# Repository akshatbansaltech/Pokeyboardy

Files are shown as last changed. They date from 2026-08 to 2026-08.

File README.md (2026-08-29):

# Pokeyboardy

<p align="center">
  <a href="https://kicanvas.org/?repo=https://github.com/akshatbansaltech/Pokeyboardy/tree/main/pcb">
    
  </a>
</p>

**Pokeyboardy** is a compact 5-key macropad which features five mechanical switches, a rotary encoder, RGB lighting, and support for a small OLED display, all powered by a Seeed Studio XIAO RP2040. The PCB, case, and knob were designed from scratch as part of the project.
The cherry on top is that its pokemon inspired!!!(yayyayay), hence the name.

POKEYBOARDY IS APPROVED IN STARDANCE!!!!!!

## Features

- 5x Cherry MX switches
- 1x EC11 rotary encoder
- 3x SK6812 mini RGB LEDs
- Seeed XIAO controller
- OLED header

## Contents

| File | What it is |
|---|---|
| [Pokeyboardy.kicad_sch](Pokeyboardy.kicad_sch) | Schematic |
| [Pokeyboardy.kicad_pcb](Pokeyboardy.kicad_pcb) | Board layout |
| [Pokeyboardy Full w components.step](Pokeyboardy%20Full%20w%20components.step) | Full case assembly |
| [Pokeyboardy Full Case.step](Pokeyboardy%20Full%20Case.step) | Case only |
| [Pokeyboardy PCB.step](Pokeyboardy%20PCB.step) | PCB model |
| [Pokeyboardy knob.step](Pokeyboardy%20knob.step) | Rotary knob |
| [production/](production/) | Gerbers zip, drill file, 3D-printable case STL files (Body/Top/Middle) + firmware |
| [Pokeyboardy.csv](Pokeyboardy.csv) | Component BOM |
| [lib/](lib/) | Footprints and 3D models used by the project |

## BOM

| Reference | Value | Footprint | Qty |
|---|---|---|-----|
| D1-D4, D8, D10 | 1N4148 DO-35 diode | Diode_THT:D_DO-35_SOD27_P7.62mm_Horizontal | 6 |
| D5, D6, D9 | SK6812 mini | LED_SMD:LED_SK6812MINI-E_3.2x2.8mm_P1.5mm_ReverseMount | 3 |
| J1 | OLED display header | Connector_PinHeader_2.54mm:PinHeader_1x04_P2.54mm_Vertical | 1 |
| SW1 | EC11 rotary encoder | Rotary_Encoder:RotaryEncoder_Alps_EC11E-Switch_Vertical_H20mm | 1 |
| SW2-SW6 | Cherry MX switch | Button_Switch_Keyboard:SW_Cherry_MX_1.00u_PCB | 5 |
| U1 | Seeed Studio XIAO RP2040 | XIAO-Generic-Hybrid-14P-2.54-21X17.8MM | 1 |

Also needed: 5x DSA keycaps, 1x 0.91" 128x32 OLED, 6x M3 heatset inserts + bolts, 3D printed case.

## Firmware

The board runs [KMK](https://github.com/KMKfw/kmk_firmware) on [CircuitPython](https://circuitpython.org/). Copy `firmware/main.py` to the CIRCUITPY drive on a XIAO RP2040 to install.

| Key (matrix order) | Action |
|---|---|
| 1 | Ctrl+C |
| 2 | Ctrl+V |
| 3 | Mute |
| 4 | Ctrl+X |
| 5 | Ctrl+Z |
| 6 (empty slot) | Ctrl+Shift+Z |
| Encoder | Volume up / down |

## Building it

1. Populate the PCB: diodes (D1-D4, D8, D10), SK6812 LEDs (D5, D6, D9), MX sockets (SW2-SW6), EC11 encoder (SW1), OLED header (J1), and the XIAO RP2040 (U1)
2. Print the case parts and drop in the heatset inserts
3. Mount the PCB in the case and screw it together
4. Flash the firmware: copy `firmware/main.py` to the CIRCUITPY drive
5. Put on the keycaps and the knob

## Schematic

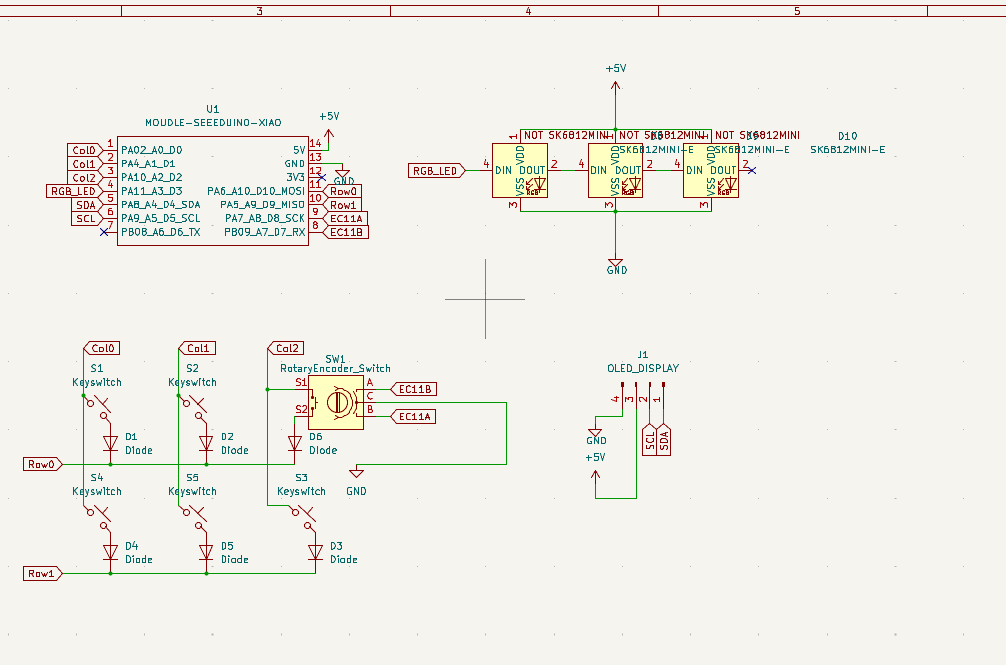
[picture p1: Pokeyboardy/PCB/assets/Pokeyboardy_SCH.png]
Schematic


## PCB

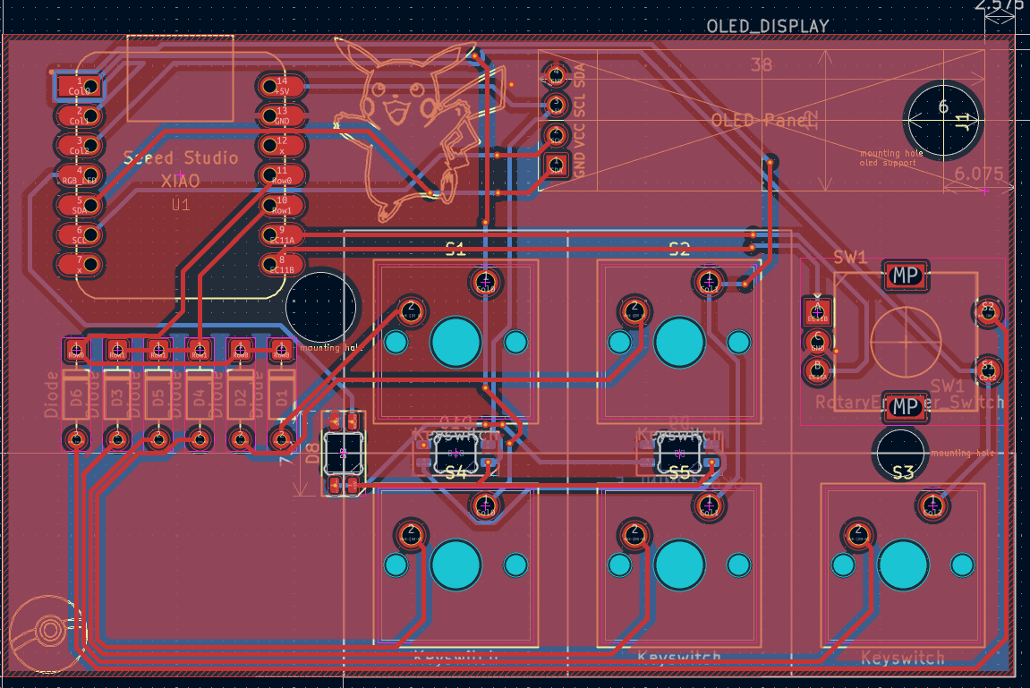
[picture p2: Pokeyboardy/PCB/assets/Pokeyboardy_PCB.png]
PCB


## CAD

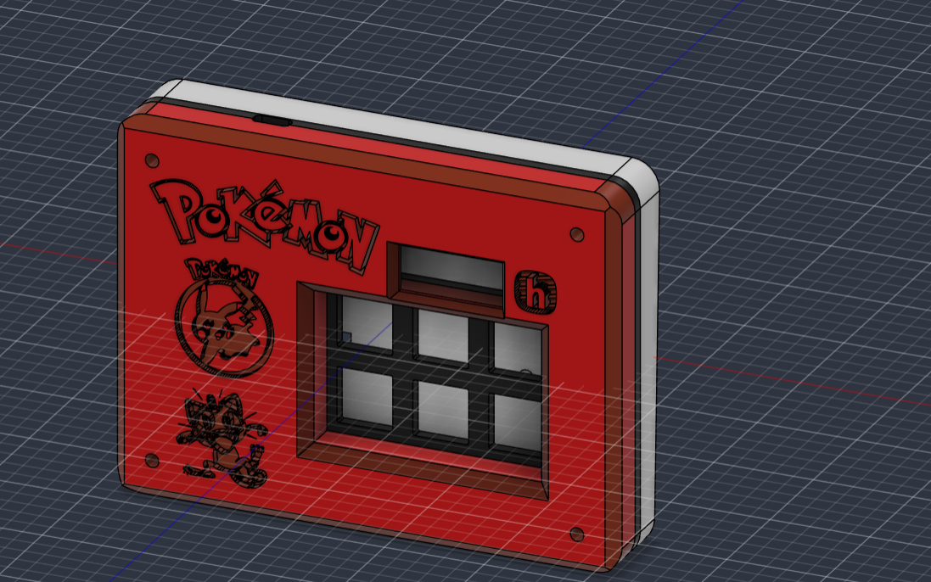
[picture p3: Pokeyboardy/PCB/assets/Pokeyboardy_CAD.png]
CAD


## License

This project is licensed under the [MIT License](LICENSE)

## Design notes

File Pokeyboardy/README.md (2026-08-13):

# Pokeyboardy

**Pokeyboardy** is a compact 5-key macropad built for Hack Club's Hackpad YSWS. It features five mechanical switches, a rotary encoder, RGB lighting, and support for a small OLED display, all powered by a Seeed Studio XIAO RP2040. The PCB, case, and knob were designed from scratch as part of the project.

## Features

- 5x Cherry MX switches
- 1x EC11 rotary encoder
- 3x SK6812 mini RGB LEDs
- Seeed XIAO controller
- OLED header

## Contents

| File | What it is |
|---|---|
| [Pokeyboardy.kicad_sch](Pokeyboardy.kicad_sch) | Schematic |
| [Pokeyboardy.kicad_pcb](Pokeyboardy.kicad_pcb) | Board layout |
| [Pokeyboardy Full w components.step](Pokeyboardy%20Full%20w%20components.step) | Full case assembly |
| [Pokeyboardy Full Case.step](Pokeyboardy%20Full%20Case.step) | Case only |
| [Pokeyboardy PCB.step](Pokeyboardy%20PCB.step) | PCB model |
| [Pokeyboardy knob.step](Pokeyboardy%20knob.step) | Rotary knob |
| [production/](production/) | Freshly generated gerbers, drill file and production zip |
| [Pokeyboardy.csv](Pokeyboardy.csv) | Component BOM |
| [lib/](lib/) | Footprints and 3D models used by the project |

## BOM

| Reference | Value | Footprint | Qty |
|---|---|---|-----|
| D1-D4, D8, D10 | 1N4148 DO-35 diode | Diode_THT:D_DO-35_SOD27_P7.62mm_Horizontal | 6 |
| D5, D6, D9 | SK6812 mini | LED_SMD:LED_SK6812MINI-E_3.2x2.8mm_P1.5mm_ReverseMount | 3 |
| J1 | OLED display header | Connector_PinHeader_2.54mm:PinHeader_1x04_P2.54mm_Vertical | 1 |
| SW1 | EC11 rotary encoder | Rotary_Encoder:RotaryEncoder_Alps_EC11E-Switch_Vertical_H20mm | 1 |
| SW2-SW6 | Cherry MX switch | Button_Switch_Keyboard:SW_Cherry_MX_1.00u_PCB | 5 |
| U1 | Seeed Studio XIAO RP2040 | XIAO-Generic-Hybrid-14P-2.54-21X17.8MM | 1 |

Also needed: 5x DSA keycaps, 1x 0.91" 128x32 OLED, 6x M3 heatset inserts + bolts, 3D printed case + 2 acrylic plates.

## Firmware

The board runs [KMK](https://github.com/KMKfw/kmk_firmware) on [CircuitPython](https://circuitpython.org/). Copy `firmware/main.py` to the CIRCUITPY drive on a XIAO RP2040 to install.

| Key (matrix order) | Action |
|---|---|
| 1 | Ctrl+C |
| 2 | Ctrl+V |
| 3 | Mute |
| 4 | Ctrl+X |
| 5 | Ctrl+Z |
| 6 (empty slot) | Ctrl+Shift+Z |
| Encoder | Volume up / down |

## Building it

1. Populate the PCB: diodes (D1-D4, D8, D10), SK6812 LEDs (D5, D6, D9), MX sockets (SW2-SW6), EC11 encoder (SW1), OLED header (J1), and the XIAO RP2040 (U1)
2. Print the case parts and drop in the heatset inserts
3. Mount the PCB in the case, add the acrylic plates and screw it together
4. Flash the firmware: copy `firmware/main.py` to the CIRCUITPY drive
5. Put on the keycaps and the knob

## Schematic

Schematic

## PCB

PCB

## CAD

CAD

## Credits

Huge thank you to Hack Club and everyone behind the [Hackpad YSWS](https://hackpad.hackclub.com/) for the parts, the guides, and the whole program - genuinely could not have built this without them.

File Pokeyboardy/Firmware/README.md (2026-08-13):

# Firmware

Pokeyboardy runs [KMK](https://github.com/KMKfw/kmk_firmware) on [CircuitPython](https://circuitpython.org/).

## Flashing

1. Put the XIAO RP2040 into bootloader mode and flash [CircuitPython](https://circuitpython.org/board/seeeduino_xiao_rp2040/) if it isn't already installed
2. Copy the `KMK` directory and its dependencies (`kmk_firmware`) onto the CIRCUITPY drive
3. Copy `KMK/main.py` to the root of the CIRCUITPY drive
4. It boots automatically — keys, encoder, RGB and OLED all work out of the box

## Layout

| Key (matrix order) | Action |
|---|---|
| 1 | Ctrl+C |
| 2 | Ctrl+V |
| 3 | Mute |
| 4 | Ctrl+X |
| 5 | Ctrl+Z |
| 6 (empty slot) | Ctrl+Shift+Z |
| Encoder | Volume up / down |

RGB runs a soft swirl by default; OLED shows the board name and encoder hint.

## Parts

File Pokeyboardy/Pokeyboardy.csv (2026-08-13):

Designator | Footprint | Quantity | Value | LCSC Part #
D1, D2, D3, D4, D5, D6 | D_DO-35_SOD27_P7.62mm_Horizontal | 6 | Diode
D10, D8, D9 | LED_SK6812MINI-E_3.2x2.8mm_P1.5mm_ReverseMount | 3 | SK6812MINI-E
J1 | SSD1306-0.91-OLED-4pin-128x32 | 1 | OLED_DISPLAY
S1, S2, S3, S4, S5 | SW_Cherry_MX_1.00u_PCB | 5 | Keyswitch
SW1 | RotaryEncoder_Alps_EC11E-Switch_Vertical_H20mm | 1 | RotaryEncoder_Switch
U1 | XIAO-Generic-Hybrid-14P-2.54-21X17.8MM | 1 | MOUDLE-SEEEDUINO-XIAO

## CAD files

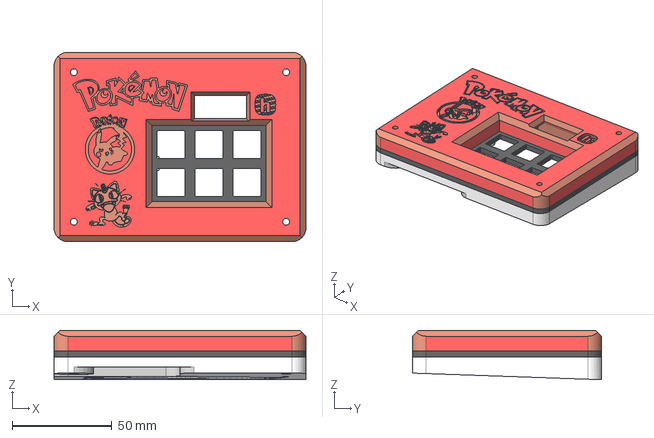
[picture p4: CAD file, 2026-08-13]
Pokeyboardy/CAD/Pokeyboardy Full Case.step
126.6 x 95.2 x 24.8 mm

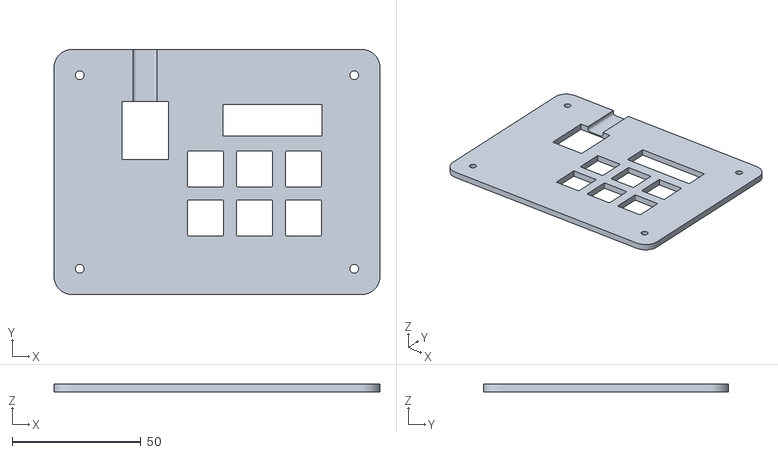
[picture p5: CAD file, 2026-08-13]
Pokeyboardy/production/Pokeyboardy Middle.stl
126.6 x 95.2 x 3.00

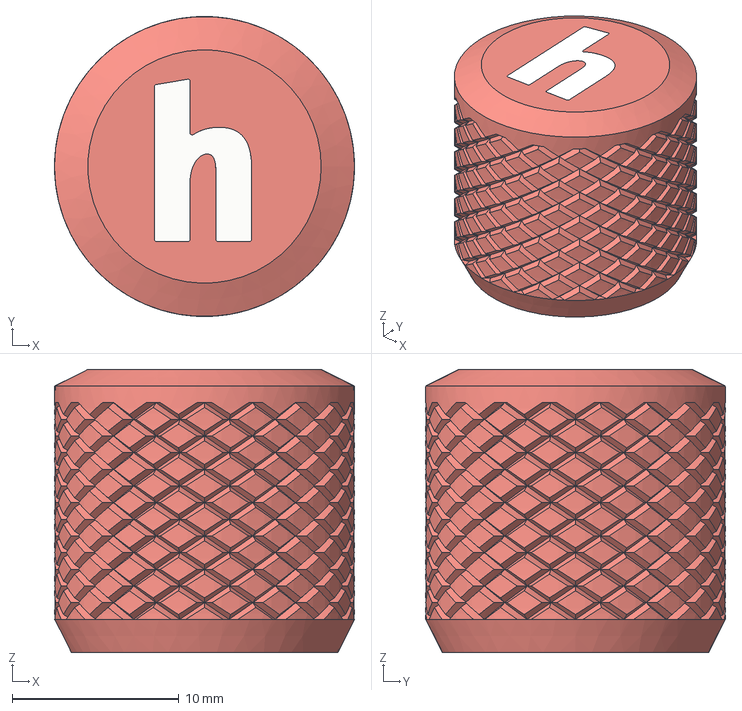
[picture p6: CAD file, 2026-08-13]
Pokeyboardy/CAD/Pokeyboardy knob.step
18.0 x 18.0 x 17.0 mm
Base
H

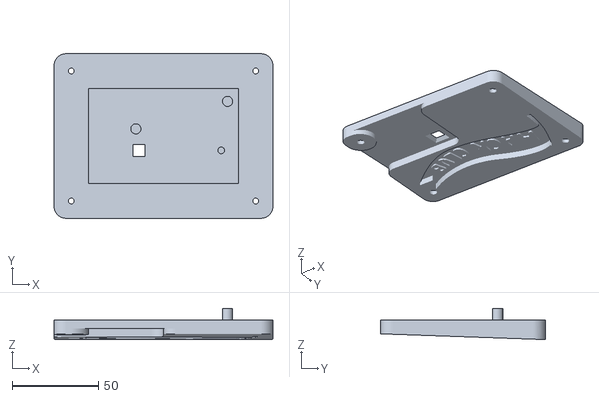
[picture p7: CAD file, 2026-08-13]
Pokeyboardy/production/Pokeyboardy Body.stl
126.6 x 95.2 x 18.0

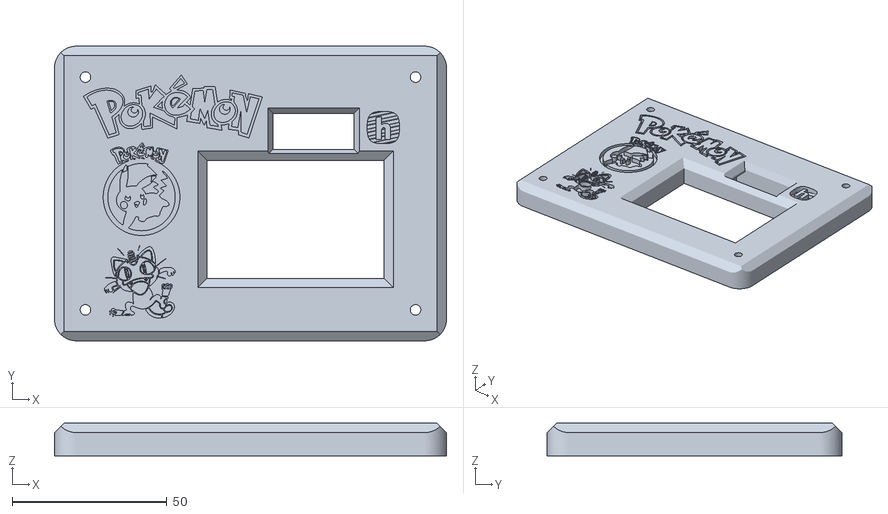
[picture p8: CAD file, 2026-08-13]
Pokeyboardy/production/Pokeyboardy Top.stl
126.6 x 95.2 x 10.5

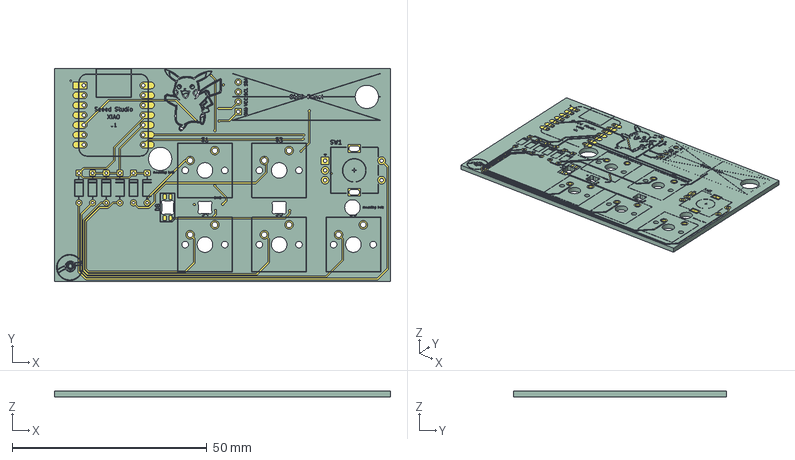
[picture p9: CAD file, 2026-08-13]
Pokeyboardy/CAD/Pokeyboardy PCB.step
86.2 x 54.8 x 1.66 mm
Pokemon Hackpad_copper
Pokemon Hackpad_silkscreen x 2
Pokemon Hackpad_PCB

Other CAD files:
Pokeyboardy/CAD/Pokeyboardy Full w components.step

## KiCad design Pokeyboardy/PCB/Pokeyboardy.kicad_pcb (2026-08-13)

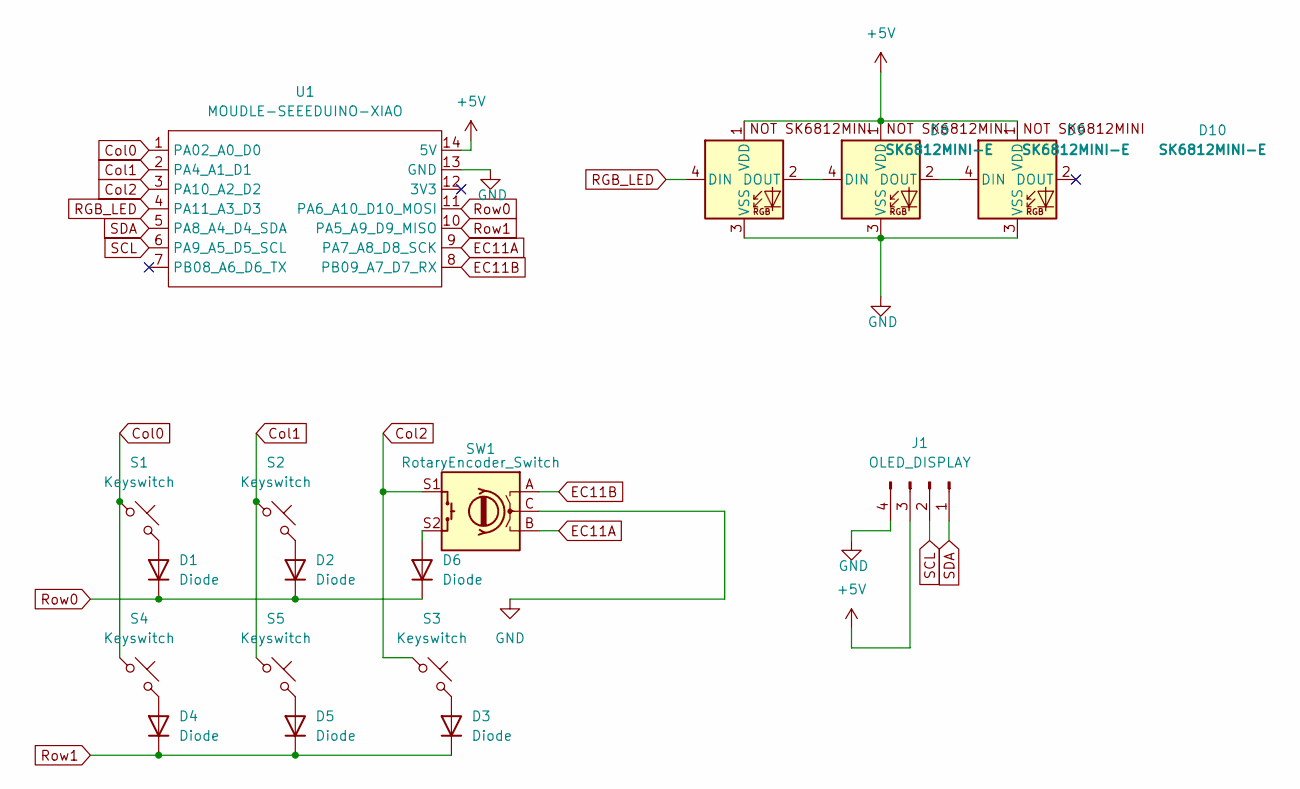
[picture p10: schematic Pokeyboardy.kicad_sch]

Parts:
D1, D2, D3, D4, D5, D6: Diode; D_DO-35_SOD27_P7.62mm_Horizontal
D8, D9, D10: SK6812MINI-E; LED_SK6812MINI-E_3.2x2.8mm_P1.5mm_ReverseMount
J1: OLED_DISPLAY; SSD1306-0.91-OLED-4pin-128x32
S1, S2, S3, S4, S5: Keyswitch; SW_Cherry_MX_1.00u_PCB
SW1: RotaryEncoder_Switch; RotaryEncoder_Alps_EC11E-Switch_Vertical_H20mm
U1: MOUDLE-SEEEDUINO-XIAO; XIAO-Generic-Hybrid-14P-2.54-21X17.8MM

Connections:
+5V: D8.1 (VDD), D9.1 (VDD), D10.1 (VDD), J1.3, U1.14 (5V)
Col0: S1.1, S4.1, U1.1 (PA02_A0_D0)
Col1: S2.1, S5.1, U1.2 (PA4_A1_D1)
Col2: S3.1, SW1.S1, U1.3 (PA10_A2_D2)
EC11A: SW1.B, U1.9 (PA7_A8_D8_SCK)
EC11B: SW1.A, U1.8 (PB09_A7_D7_RX)
GND: D8.3 (VSS), D9.3 (VSS), D10.3 (VSS), J1.4, SW1.C, U1.13 (GND)
unnamed: D1.2 (A), S1.2
unnamed: D2.2 (A), S2.2
unnamed: D3.2 (A), S3.2
unnamed: D4.2 (A), S4.2
unnamed: D5.2 (A), S5.2
unnamed: D6.2 (A), SW1.S2
unnamed: D8.2 (DOUT), D9.4 (DIN)
unnamed: D9.2 (DOUT), D10.4 (DIN)
RGB_LED: D8.4 (DIN), U1.4 (PA11_A3_D3)
Row0: D1.1 (K), D2.1 (K), D6.1 (K), U1.11 (PA6_A10_D10_MOSI)
Row1: D3.1 (K), D4.1 (K), D5.1 (K), U1.10 (PA5_A9_D9_MISO)
SCL: J1.2, U1.6 (PA9_A5_D5_SCL)
SDA: J1.1, U1.5 (PA8_A4_D4_SDA)

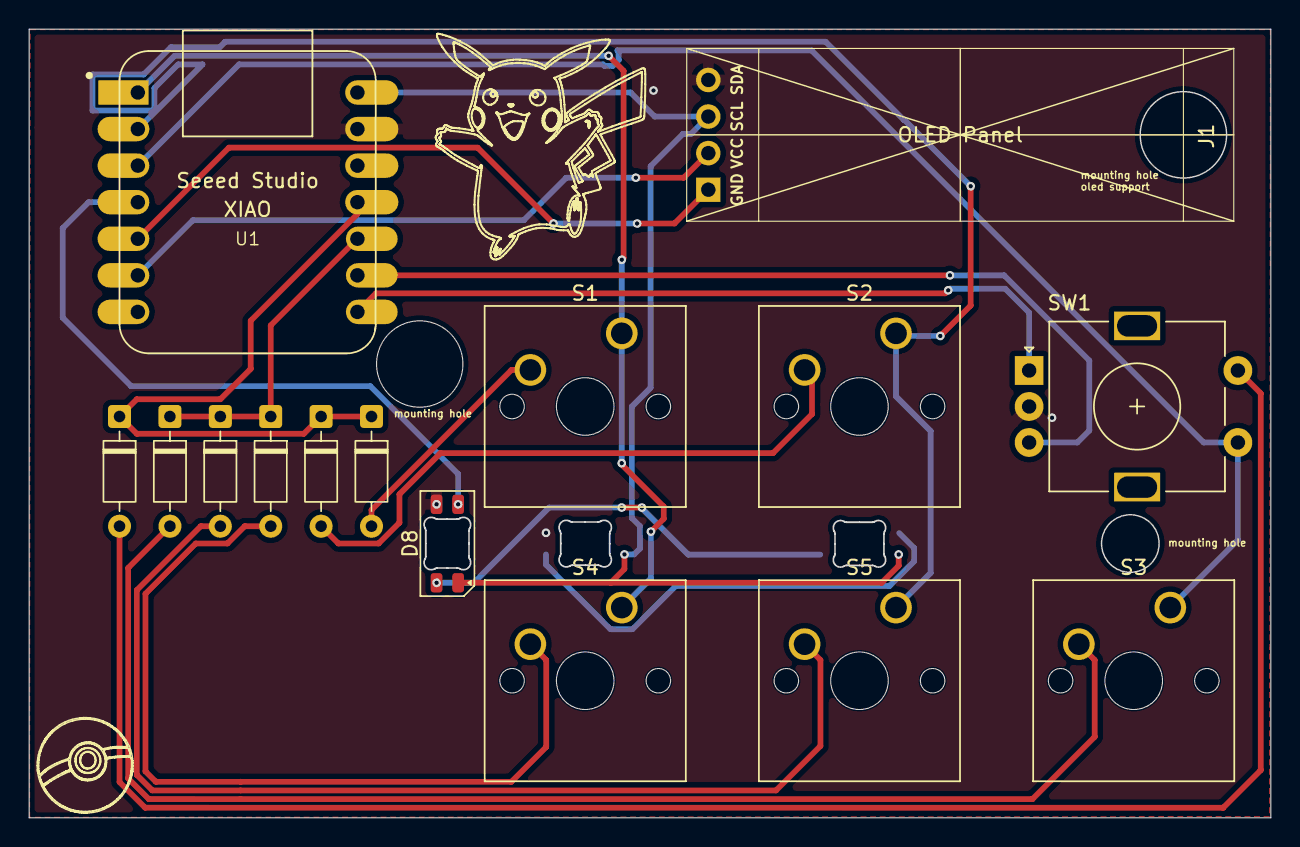
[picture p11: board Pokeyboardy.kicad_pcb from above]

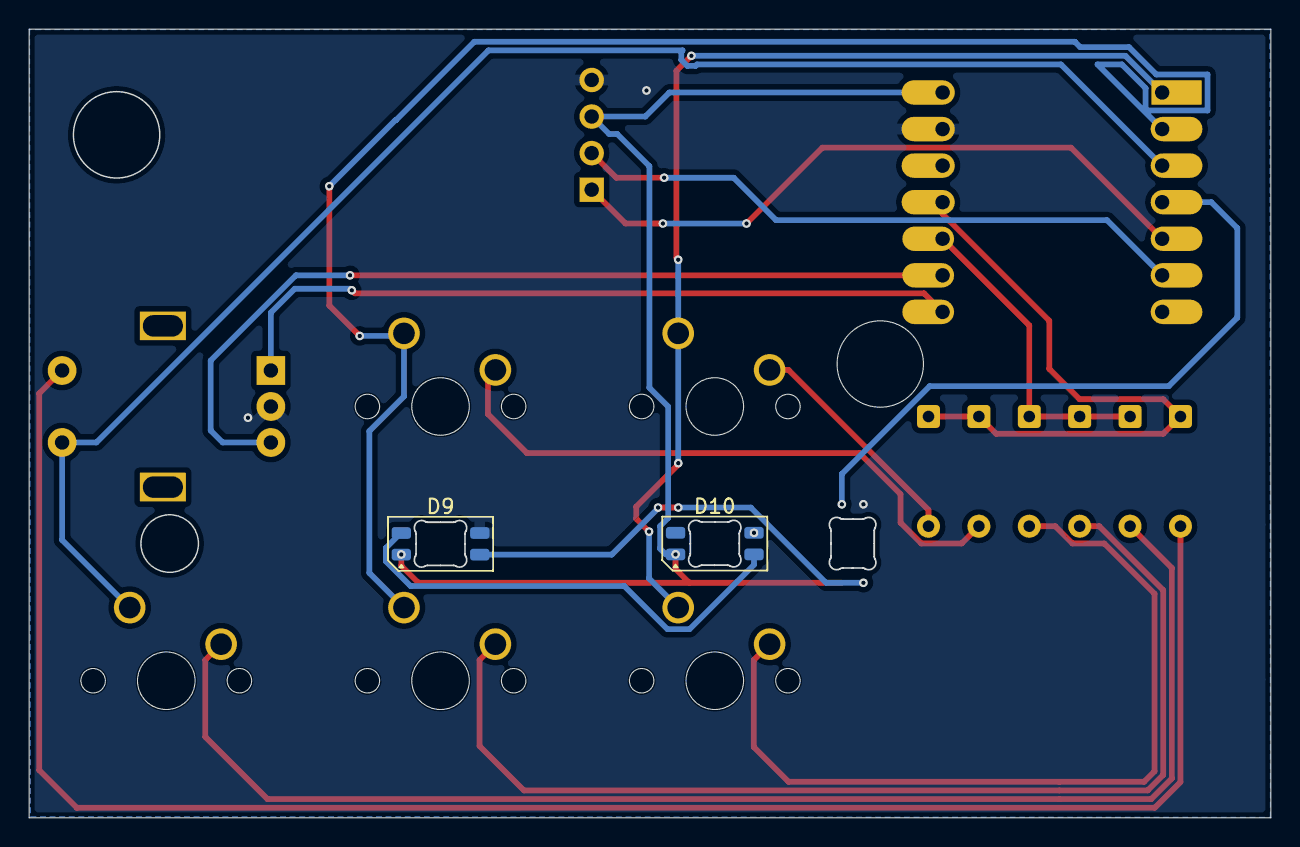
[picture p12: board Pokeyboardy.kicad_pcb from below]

Board: 2 copper layers, 86.2 x 54.8 mm, 17 parts (2 on the bottom side), 20 nets.

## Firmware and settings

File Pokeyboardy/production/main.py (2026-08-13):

import board
import busio
import displayio

from kmk.kmk_keyboard import KMKKeyboard
from kmk.keys import KC
from kmk.matrix import DiodeOrientation
from kmk.modules.encoder import EncoderHandler
from kmk.extensions.rgb import RGB, AnimationModes
from kmk.extensions.display import Display, TextEntry
from kmk.extensions.display.ssd1306 import SSD1306

keyboard = KMKKeyboard()

keyboard.col_pins = (board.GP26, board.GP27, board.GP28)
keyboard.row_pins = (board.GP3, board.GP4)
keyboard.diode_orientation = DiodeOrientation.COL2ROW

encoder_handler = EncoderHandler()
encoder_handler.pins = ((board.GP2, board.GP1, None),)
encoder_handler.map = ((KC.VOLU, KC.VOLD),)
keyboard.modules.append(encoder_handler)

rgb = RGB(
    pixel_pin=board.GP29,
    num_pixels=2,
    animation_mode=AnimationModes.SWIRL,
    hue_default=60,
    sat_default=80,
    val_default=60,
    animation_speed=1.5,
)
keyboard.extensions.append(rgb)

# 0.91in 128x32 ssd1306 oled over i2c on gp6 sda gp7 scl
displayio.release_displays()
i2c_bus = busio.I2C(board.GP7, board.GP6)
driver = SSD1306(i2c=i2c_bus, device_address=0x3C)
display = Display(
    entries=[
        TextEntry(text='Pokeyboardy', x=0, y=0),
        TextEntry(text='enc: volume', x=0, y=2, x_anchor='L', y_anchor='T'),
    ],
    width=128,
    height=32,
    driver=driver,
)
keyboard.extensions.append(display)

keyboard.keymap = [
    [
        KC.LCTL(KC.C), KC.LCTL(KC.V), KC.MUTE,
        KC.LCTL(KC.X), KC.LCTL(KC.Z), KC.LSFT(KC.LCTL(KC.Z)),
    ]
]

if __name__ == '__main__':
    keyboard.go()

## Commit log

2026-08-13 start the kicad project - pcb, schematic and board settings
    [Pokeyboardy.kicad_pcb, Pokeyboardy.kicad_sch]
2026-08-13 add the footprint libraries and 3d models
2026-08-13 add the cad files for the case, pcb and knob
    [Pokeyboardy Full Case.step, Pokeyboardy Full w components.step, Pokeyboardy PCB.step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]
2026-08-13 add the bom
    [Pokeyboardy.csv]
2026-08-13 show the schematic in the readme
2026-08-13 rework the keymap - cut, undo and redo on the second row
    [main.py]
2026-08-13 show the encoder action on the oled
2026-08-13 regenerate production files from the current pcb
    [Pokeyboardy-B_Courtyard.gbr, Pokeyboardy-B_Cu.gbl, Pokeyboardy-B_Fab.gbr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]
2026-08-13 export the case parts as stl and tidy the production folder
    [Pokeyboardy Body.stl, Pokeyboardy Middle.stl, Pokeyboardy Top.stl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]
2026-08-13 organize into pcb and firmware folders
    [Pokeyboardy.kicad_pcb, Pokeyboardy.kicad_sch]
2026-08-13 move the cad files into their own folder
    [Pokeyboardy Full Case.step, Pokeyboardy Full w components.step, Pokeyboardy PCB.step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]
2026-08-13 keep the lib tables out of the pcb folder
2026-08-13 wrap everything in a pokeyboardy folder
    [Pokeyboardy Body.stl, Pokeyboardy Full Case.step, Pokeyboardy Full w components.step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]
2026-08-13 leave only the stl and firmware in production
2026-08-13 move the gerbers into production
2026-08-13 ignore kicad lock files and autosave history
2026-08-13 ignore all kicad autosave history folders
2026-08-13 list the gerbers and stl files in the contents table
2026-08-13 regenerate the full set of gerbers and drill files
    [Pokeyboardy-B_Courtyard.gbr, Pokeyboardy-B_Cu.gbl, Pokeyboardy-B_Fab.gbr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]
2026-08-13 keep production to the zip plus stls and firmware
    [Pokeyboardy-B_Courtyard.gbr, Pokeyboardy-B_Cu.gbl, Pokeyboardy-B_Fab.gbr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]
2026-08-13 drop the acrylic plates from the bill of materials
2026-08-13 Add PCB KiCanvas badge to README
2026-08-13 Center PCB badge in README
2026-08-28 add proper gerbers
